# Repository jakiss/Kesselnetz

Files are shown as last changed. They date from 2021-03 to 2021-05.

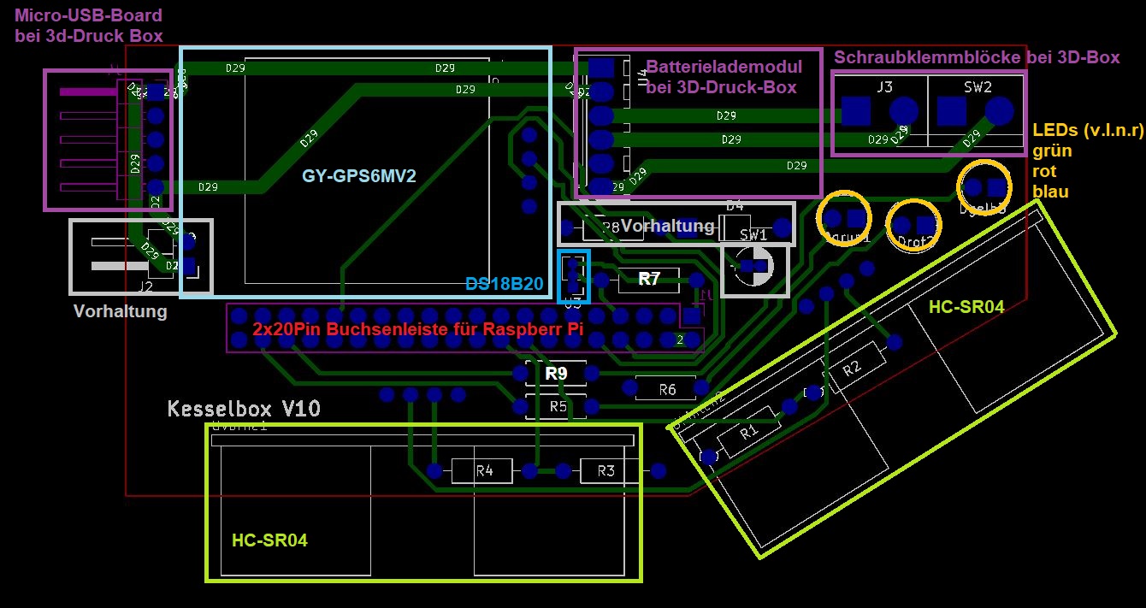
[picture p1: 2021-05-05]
Hardware/Platine_Draufsicht_1.JPG

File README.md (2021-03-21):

# Kesselbox
For the enlish version see below.

Das Projekt befasst sich mit der Entwicklung eines Radmessers nach der Idee des Tagesspiegel Berlin (Vgl. https://interaktiv.tagesspiegel.de/radmesser/ und https://github.com/tagesspiegel/radmesser). 

Die genaue des Beschreibung des Projekts mit Grundidee und Annahmen findet sich unter Projektbeschreibung.pdf, um eine kurze Zusammenfassung zu erhalten empfiehlt sich die Datei Zusammenfassung_Projektbeschreibung.pdf.

Das Projekt darf unter der GNU General Public License (GPL) verwendet werden.

------------------------------------------------------------
English version:

The project deals with the development of a measurement system for the overtaking distance between cars and bicycles after the idea of the Tagesspeigel Berlin (see https://interaktiv.tagesspiegel.de/radmesser/ and https://github.com/tagesspiegel/radmesser).

The detailed description of the project including the main idea and assumptions  can be found in Projektbeschreibung.pdf. For a short summary of the topic the file Zusammenfassung_Projektbeschreibung.pdf is recommended.

The project can be reused under the GNU General Public License (GPL).

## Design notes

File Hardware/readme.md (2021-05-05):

# Hardware

## Materialliste allgemein

| Komponentenname | Zahl pro Bausatz | Anmerkung |
| --- | --- | --- |
| Raspberry Pi Zero W | 1 | ohne vorgelötete Pins|
| Micro SD-Karte | 1 | mind. 16GB Class 10 |
| Buchsenleiste | 1 | 2x20 Pins 2,54mm RM |
| Steckerleiste | 1 | 2x20 Pins 2,54mm RM |
| Ultraschallsensoren | 2 | HC-SR04 |
| Widerstand | 2 | 510 Ohm |
| Widerstand | 2 | 1 kOhm |
| Widerstand | 1 | 4,7 kOhm |
| Widerstand | 3 | 100 Ohm |
| GPS-Modul | 1 | GY-GPS6MV2 mit Antenne |
| Temperatursensor | 1 | DS18B20 |
| Stiftleiste | 1 | 1x4 Pins RM 2,54 mm |
| LED | 3 | grün, rot, blau jeweils 5 mm |
| Powerbank | 1 | Kapazität von 5000 mAh empfohlen |

## Materialliste bei Montage in 3D-gedruckter Box (zusätzlich)

| Komponentenname | Zahl pro Bausatz | Anmerkung |
| --- | --- | --- |
| Akkus | 2 | 3,6V Wiederaufladbare Akkus 18650 (Flat-Top Li-Ion 3.6 V) |
| Akkuhalter | 1 | Passend für 2 Akkus 18650 |
| Micro-USB-Breakout-Board | 1 | |
| Steckerleiste | 1 | 1x5 Pin RM 2,54 mm |
| Batterielademodul | 1 | für Lithium Batterien 18650 (MakerHawk) |
| Steckerleiste | 1 | 1x6 Pin RM 2,54 mm |
| Wippschalter | 1 | |
| Schraubklemmblock | 2 | 2 polig RM 5,08 mm |
| Litze und Adernendhülsen | | Anschluss zwischen Schraubklemmblock und Schalter und Batteriehalter|

Powerbank wird nicht benötigt

# Montagereihenfolge

## allgemeine Montagereihenfolge

| Arbeitsschritt | zu verlötendes Bauteil |
| --- | --- |
| 1. | Wiederstände löten |
| 1.1 | 510 Ohm R2 und R4 |
| 1.2 | 1 kOhm R1 und R3 |
| 1.3 | 100 Ohm R5, R6 und R9 |
| 2. | LEDS löten, links grün, mitte rot, rechts blau |
| 3. | Buchsenleiste für Raspberry Pi anlöten, Raspberry Pi mit Steckerleiste versehen, Raspberry Pi erst zum Schluss aufstecken |
| 4. | Temperatursensor DS18B20 anlöten |
| 5. | GPS-Modul mit 4 Pin-Sitftleiste anlöten, Antenne befestigen | 
| 6. | Ultraschallsensoren anlöten |

## zusätzliche Schritte bei 3D-Druck-Box 

| Arbeitsschritt | zu verlötendes Bauteil |
| --- | --- |
| 1. | Batterielademodul mit 6-Pol-Stiftleiste verlöten |
| 2. | Micro-USB-Board mit 5-Pol-Stiftleiste verlöten |
| 3. | Schraubklemmenblock verlöten |
| 4. | Schalter an den rechten Schraubklemmenblock anschliessen |
| 5. | Batteriehalter an den linken Schraubklemmenblock anschliessen | 

# Software

| Arbeitsschritt | zu installierende Software-Komponente |
| --- | --- |
| 1. | Betriebssystem installieren - Raspbian wird mit Hilfe von Win32DiskImager auf die Micro-SD-Karte gespielt |
| 2. | Schnittstellen freigeben - in den Einstellungen werden I2C und die W-1 Schnittstellen freigegeben |
| 3. | Python-Code auf dem Raspberry Pi speichern |
| 4. | Test der Komponenten über die Testsoftware |
| 5. | Auto-Start definieren - in der Datei /etc/rc.local den Eintrag python3/Dateispeicherort/Dateiname & hinzufügen |

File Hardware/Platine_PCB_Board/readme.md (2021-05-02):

# Platine

Die Platine wurde mittels KiCad entworfen.

Die aktuellste Version stellt die V10 dar.

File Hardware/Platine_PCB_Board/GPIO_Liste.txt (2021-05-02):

GPIO16 (36) LED gelb
GPIO18 (12) LED grün
GPIO20 (38) LED rot
GPIO25 (22) Trigger
GPIO24 (18) Echo Vorne
GPIO23 (16) Echo Hinten
GPIO6  (31) Taster

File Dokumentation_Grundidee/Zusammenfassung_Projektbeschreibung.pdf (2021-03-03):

(T3 3000) – Jahrgang 2017

MESSSYSTEM ZUR BESTIMMUNG VON UBERHOLABST ¨ | ANDEN ¨

## VON KRAFTFAHRZEUGEN GEGENUBER FAHRRADFAHRERN ¨

Jakob Seitzer
Elektrotechnik, TEL17GR5, DHBW Stuttgart
Kurzfassung: Die Arbeit beschaftigt sich mit der Entwicklung eines Messsystems zur Ermittlung der ¨ | Uberhol- ¨
abstande von Kraftfahrzeugen gegen ¨ | uber Fahrradfahrern. Zur Bestimmung der seitlichen Abst ¨ | ande werden Ul- ¨
traschallsensoren (HC-SR04) verwendet, welche an einem Raspberry Pi Zero angebunden sind. Ein Temperatursensor (DS18B20) wird zur Kompensation der Temperaturabhangigkeit der Abstandsmessung verwendet. ¨ Das GPS-Modul GY-GPS6MV2 wird zur Bestimmung von Zeit und Position verwendet. Mit Hilfe einer Auswer-
tungssoftware werden Uberholvorg ¨ | ange aus den aufgezeichneten Daten extrahiert. ¨
Sch ¨usselworter: ¨ | Uberholabstand, Abstandsmessung, Ultraschallsensoren, HC-SR04, GPS-Modul ¨

Abstract: This student research project deals with the construction of a measurement system for recording overtakindg distances between motor wehicels and byciles. For measuring the distance on the left side of the bycile, two ultrasonic ranging sensors (HC-SR04) are used and connected to a Raspberry Pi Zero. A temperature sensor (DS18B20) is used for compensation of tempreature dependency of the distance measurement. The GPS-receiver GY-GPS6MV2 is used for detection of position and time. With a evaluation software the overtaking actions are detectet in the measured data.

Keywords: overtaking distance, distance measurement, ultra sonic raning module, HC-SR04, GPS-receiver

### 1 EINFUHRUNG ¨

Am 28.04.2020 trat die aktuell letzte Anderung der Straßenverkehrsordnung in Kraft. Zentrale Anpassung stellte ¨
hierbei die genaue Festlegung des Mindestuberholabstandes von Kraftfahrzeugen gegen ¨ | uber Fahrradfahrern ¨
dar. Innerorts muss beim Uberholen ein seitlicher Abstand von mindestens ¨ | | | 1,5 m eingehalten werden - außerorts
mindestens 2 m.
In einer groß angelegten Studie des Tagesspiegel Berlin aus dem Jahr 2018, wurde versucht die Uberholabst ¨ | ande ¨
gegenuber Fahrradfahrern in Berlin zu dokumentieren [ ¨ | 1]. Der entwickelte Radmesser ist nicht frei verfugbar. ¨
Aus diesem Grund konnen die Daten nicht unabh ¨ | angig gepr ¨ | uft werden. Es bestehen noch weitere Konzepte ¨
zur Konstruktion eines Radmessers, diese sind jedoch nicht vollstandig funktionsf ¨ | ahig [ ¨ | 2]. Um die Ergebnisse
der Studie des Tagesspiegels zu uberpr ¨ | ufen und auch Daten ¨ | uber andere St ¨ | adte zu erhalten, soll ein offenes ¨
Messsystem zu Erfassung der Uberholabst ¨ | ande entwickelt werden. ¨

### 2 SYSTEMBESCHREIBUNG

Fur das Erfassen der ¨ | Uberholabst ¨ | ande wird ein Messsystem entwickelt werden, welches am Fahrrad montiert ¨
wird und automatisch die Abstande nach links aufzeichnet. Mit Hilfe einer Software werden anschließend die ¨
Uberholabst ¨ | ande aus den gewonnenen Daten extrahiert. ¨

### 2.1 Hardwarekomponenten

Als zentrales Hardwareelement wird eine Recheneinheit benotigt, welche mit den Abstandssensoren kommu- ¨ nizieren kann. Um eine unabhangige und einfache Funktionsweise zu erreichen, wird mit dem Raspberry Pi ¨
Zero gearbeitet. Dieser stellt 40 GPIO-Pins zur Verfugung, an welche Sensoren angeschlossen werden k ¨ | onnen. ¨
Mit der Sprache Python 3 wird eine Software fur das Messsystem auf dem Raspberry Pi entwickelt. Auf der ¨ Micro-SD-Karte des Raspberry Pis werden die gemessenen Daten gespeichert werden.

Um den Uberholabstand zu erfassen werden zwei Ultraschallsensoren verbaut. Als Standardbauteil im unteren ¨
Preissegment fur Abstandssensoren bietet sich der Ultraschallsensor HC-SR04 an. Dieser erfasst zuverl ¨ | assig ¨
einen Messbereich zwischen 4 cm und 5 m und wird in vielen studentischen Projekten verwendet [3] [4]. Die Messung erfolgt nach einem Triggerimpuls von 10 µs. Es werden Schallwellen mit einer Frequenz von 40 kHz
ausgesendet und der Ruckmelde-Pin des Sensors geht auf ¨ | High. Wird der ausgegeben Schall innerhalb von

38 ms wieder empfangen, geht der Ruckmelde-Pin zum Empfangszeitpunkt wieder auf ¨ | Low, ansonsten nach
tmax = 38 ms.

Bei der Verwendung eines Ultraschallsensors muss die Temperaturabhangigkeit der Schallgeschwindigkeit be- ¨
rucksichtigt werden. Im Einsatzbereich des Messsystems ist mit Temperaturen zwischen ¨ | −10 °C und 35 °C, was
eine Abweichung der Schallgeschwindigkeit von bis zu 10 % zur Folge hat. Um die Temperaturabhangigkeit ¨ auszugleichen, wird die Temperatur mit dem Temperatursensor DS18B20 bestimmt. Dieser zeichnet sich durch
einen gunstigen Preis und eine weite Verbreitung in anderen Projekten aus [ ¨ | 5] [6].
Bei dem GPS-Modul, welches fur die Positions- und Zeitbestimmung ben ¨ | otigt wird, gibt es kaum etablierte ¨
Bauteile. Nach ausfuhrlicher Recherche fiel die Entscheidung auf das GPS-Modul NEO-6 der Firma u-blox. F ¨ | ur¨
die vereinfachte Konnektivitat hin zum Raspberry Pi Zero wird das Modul GY-GPS6MV2 verwendet, auf welchem ¨
der Chip NEO-6 verbaut ist. Dieses Modul ist kostengunstig erh ¨ | altlich und kann ¨ | uber die Universal Asynchronous ¨
Receiver Transmitter-Schnittstelle (UART) mit dem Raspberry verbunden werden [7].
Die Uberholvorg ¨ | ange werden durch die unterschiedlichen Zeitpunkte bestimmt, zu welchen das Kraftfahrzeug ¨
von den beiden Ultraschallsensoren erfasst wird. Um eine zeitlich unterschiedliche Erfassung durch die Ultraschallsensoren zu erreichen, mussen diese entweder in einem ausreichenden Abstand voneinander ent- ¨ fernt montiert sein, oder in zwei unterschiedliche Richtungen messen. Zuerst muss in diesem Zusammenhang bestimmt werden, welche maximale Distanz lmax ein Kraftfahrzeug zwischen zwei Messungen der Ul-
traschallsensoren zurucklegt. Innerhalb von St ¨ | adten ist mit einer maximalen Geschwindigkeitsdifferenz von ¨
vmax = 70 km h⁻¹ ≈ 19,44 m s⁻¹ zwischen Radfahrer und Kraftfahrzeug beim Uberholen zu rechnen. ¨
lmax = vmax · tmax = 0,038 ms · 19,44 m s⁻¹ = 0,739 m | (1)
Die Montage der beiden Ultraschallsensoren ist nicht in einem Abstand von 70 cm moglich, da der zur Verf ¨ | ugung ¨
stehende Platz auf dem Fahrrad begrenzt ist. Deshalb mussen die Ultraschallsensoren in zwei unterschiedliche ¨ Richtungen messen. Der minimale Winkel αmin, welchen die Ultraschallsensoren voneinander abgewandt sein
mussen, wird mit Hilfe der berechneten Strecke ¨ | lmax und einer angenommenen Messdistanz von lMess = 1,5 m
bestimmt. Es gilt die Annahme, dass bei α = 0° die Ultraschallsensoren das Kraftfahrzeug zeitgleich erkennen.

αmin = arctan

lmax

lMess

=

0,739 m
1,5 m
= 26,23° | (2)
Es besteht die Moglichkeit entweder einen Ultraschallsensor um mindestens ¨ | αmin = 26,33° vom anderen abzu-
wenden, oder beide um mindestens αmin/2 = 13,17° gegeneinander zu verstellen. Um genauere Messergebnisse zu erzielen, werden beide Ultraschallsensoren um αmin/2 verdreht. Bei dieser Montageart ist der Winkel zwischen Ultraschallsensor und Kraftfahrzeug geringer und die Messabweichung fallt geringer aus. ¨
Alle benotigten Bauteile werden auf eine in KiCad entwickelten Leiterplatte gel ¨ | otet. Dies bietet sowohl die ¨
Moglichkeit einer dauerhaften und sicheren Montage, als auch eine exakte Positionierung der Ultraschallsen- ¨
soren bezuglich des Winkels ¨ | α.

### 2.2 Software f ¨ur das Messsystem

Wie bereits oben beschrieben, kann auf dem Raspberry Pi ein Programm in Python 3 entwickelt werden. Drei zentrale Anforderungen muss das Programm erfullen: ¨

1. Moglichst viele Abstandsmessungen ¨
2. Hohe Ausfallsicherheit
3. Hohe Datensicherheit
Moglichst viele Messungen ¨ | mit den Ultraschallsensoren sorgen fur eine solide Datenlage. Hierf ¨ | ur werden ¨
die beiden Ultraschallsensoren durch den selben Impuls getriggert, sie starten zeitgleich ihre Messungen.
Die Ruckmelde-Pins werden durch die Software ¨ | uberwacht. Sobald einer der beiden Pins auf ¨ | High ist, wird
dieser Zeitpunkt als Startzeitpunkt fur den Ultraschallsensor verwendet. Befinden sich beide R ¨ | uckmelde-Pins ¨
im High-Zustand, wird uberwacht, wie lange sie in diesem Zustand verbleiben. F ¨ | allt ein R ¨ | uckmelde-Pin wie- ¨
der auf Low, ist dessen Messung beendet und die Zeit tMess, kann zusammen mit der Schallgeschwindigkeit cSchall = 340 m s⁻¹ zur Ermittlung der Messdistanz verwendet werden. Unter Berucksichtigung, dass der Schall ¨
in der Zeit tmess sowohl Hin- als Ruckweg zum Kraftfahrzeug zur ¨ | uck gelegt hat, bestimmt sich die Entfernung ¨
des KFZ lMess zu

lMess =

1
- tMess · cSchall | (3)

Sobald beide Ultraschallsensoren ihre Messung beendet haben und das Messergebnis in einer CSV-Datei gespeichert wurde, wird unmittelbar im Anschluss wieder eine neue Messung initiiert. Das Erfassen der Zeit und Postion ist weniger oft notwendig, da zwischen zwei erfassten Positionen interpoliert werden kann, solange diese nicht zu weit voneinander entfernt sind. Als maximaler zeitlicher Abstand tGP Smax ergibt sich aus einem
maximalen raumlichen Abstand, bei welchem noch interpoliert werden kann, von ¨ | lGP Smax = 20 m und einer
maximalen Geschwindigkeit des Fahrradfahrers von vbikemax = 30 km h⁻¹ = 8,33 m s⁻¹
| :

tGP Smax =

lGP Smax

vbikemax

| | = 2,4 s | (4)

Die Temperaturmessung nimmt eine Zeit von bis zu 750 ms in Anspruch [6] und wird deshalb nur in Minuten-
abstanden durchgef ¨ | uhrt. Eine starke Temperaturschwankung ist w ¨ | ahrend einer Fahrradfahrt nicht zu erwarten, ¨
jedoch zwischen verschiedenen Fahrten. Um den Speicherverbrauch moglichst gering zu halten, wird drauf ¨ verzichtet die Postions- und Temperaturdaten zu jedem Messwert der Ultraschallsensoren hinzuzufugen. Diese ¨ werden lediglich einmal als eigene Zeile zum Zeitpunkt der Messung abgelegt.
Ein Eingriff in das Messsystem ist wahrend des Betriebs nicht m ¨ | | oglich und macht deshalb eine ¨ | hohe Ausfallsi-
cherheit erforderlich. Daten mussen zuverl ¨ | assig aufgezeichnet werden. Aus diesem Grund ist ein Stehenbleiben ¨
oder Abbruch des Programms zu verhindern. Durch das sofortige und standige Wiederholen der Messungen ¨ mit den Ultraschallsensoren besteht die Gefahr, dass nicht alle Messungen reibungslos Ablaufen. Wird ein Triggerimpulses nicht korrekt erkannt, wird der normale Messzyklus durchbrochen. Durch Uberwachung der Zeit, ¨
welche das Programm fur eine Abstandsmessung ben ¨ | otigt, wird beim ¨ | Uberschreiten einer Zeitgrenze von ¨ | 50 ms
die Messung beendet. Zudem wird dem Benutzer durch eine Betriebsstatusanzeige bestehend aus zwei LEDs signalisiert, ob ein reibungsloser Programmdurchlauf gewahrleistet ist. Zu Programmstart werden die einzelnen ¨ Komponenten getestet, bevor die Statusanzeige auf betriebsbereit (grune LED) wechselt. Wird ein Sensor als ¨ fehlend oder fehlerhaft erkannt, wird dies dem Nutzer durch eine rote LED signalisiert. Eine Problembehebung muss im Einzelfall erfolgen.

Wahrend einer Messfahrt sind verschiedene Szenarien denkbar, welche zu einem Absturz des Raspberry Pis ¨
fuhren k ¨ | onnen und nicht softwaretechnisch abgefangen werden k ¨ | onnen. Ein Spannungsausfall, entweder durch ¨
eine leere Powerbank oder das Herausrutschen eines Kabels sind ebenso denkbar, wie ein Unfall und eine damit einhergehende Beschadigung des Messsystems bzw. der Recheneinheit. Um die bis zu diesem Zeitpunkt ¨ erfassten Daten nicht zu verlieren, ist eine hohe Datensicherheit erforderlich. In diesem Zusammenhang ist zu berucksichtigen, dass die Datei, welche zum Zeitpunkt des Programmabsturzes beschrieben wird, unbrauchbar ¨ wird und alle darin enthaltenen Daten verloren gehen. Um den Datenverlust zu minimieren, wird nach einer festgelegten Zahl an Messungen (5000) die bisherige Datei geschlossen und eine neue Datei mit fortlaufender Nummerierung erstellt, in welche die neuen Daten gespeichert werden. So gehen maximal 5000 Messwerte verloren, das bedeutet die Messwerte von maximal zwei Minuten.

### 2.3 Auswertungssoftware f ¨ur die Messdaten

Als Auswertungsgrundlage dienen die durch die Messsoftware erstellten CSV-Dateien, welche die gemessenen Abstandswerte, Positionen und Temperaturen beinhalten. Nach dem anfanglichen Einlesen der gemessenen ¨ Daten, welches das Zuweisen der Positions- und Temperaturdaten zu den Abstandsmesswerten beinhaltet, so-
wie die Glattung der gemessenen Abst ¨ | ande, werden diese auf ¨ | Uberholvorg ¨ | ange untersucht. Kennzeichnend ¨
fur¨ Uberholvorg ¨ | ange ist ein Abfallen des Messwerts des hinteren Ultraschallsensors, w ¨ | ahrend der vordere Ul- ¨
traschallsensor weiterhin eine große Distanz erfasst. Danach ermitteln beide Ultraschallsensoren den gleichen kleinen Abstandswert, da sich das Kraftfahrzeug genau neben dem Fahrrad befindet und von beiden Ultraschallsensoren erfasst wird. Zum Ende des Uberholvorgangs steigt der Messwert des hinteren Ultraschallsensors an, ¨ wohingegen der vordere Ultraschallsensor weiterhin das Kraftfahrzeug erfasst und einen kleinen Messwert liefert.
Da jedem Uberholvorgang GPS-Koordinaten zugeordnet sind, ist eine Analyse der ¨ | Uberholvorg ¨ | ange nach Re- ¨
gionen moglich. Um eine exakte regionale Analyse zu erhalten werden die Koordinaten in Adressen bestehend ¨ aus Stadt, Postleitzahl und Straße umgewandelt. Anhand dieser Informationen kann ein Vergleich zwischen
verschiedenen Stadten erfolgen. Innerhalb einzelner St ¨ | adte k ¨ | onnen besonders gef ¨ | ahrliche Straßenabschnitte ¨
erkannt werden. Um die GPS-Koordinaten in Adressen umzuwandeln wird eine Programmierschnittstelle ver-
wendet (Application Programming Interface - API). Aus Kosten- und Kompatibilitatsgr ¨ | unden wird mit der API von ¨
OpencageGeocoder gearbeitet. Nach Ubergabe der Koordinaten wird die dazugeh ¨ | orige Straße gesucht und ¨
die gefundene Adresse mit Informationen uber die Straße (Straßentyp, erlaubte Geschwindigkeit, Anzahl der ¨
Fahrspuren) zuruckgegeben [ ¨ | 8].

### 3 TESTS

### 3.1 Hardwaretests

HC-SR04

la=Messdistanz

lb=seitliche Abweichung

# lc=gemessene Distanz

β

Abbildung 1: Messbereich | der | Ultraschallsensoren
HC-SR04, in Farbe die eingesetzten Objekte

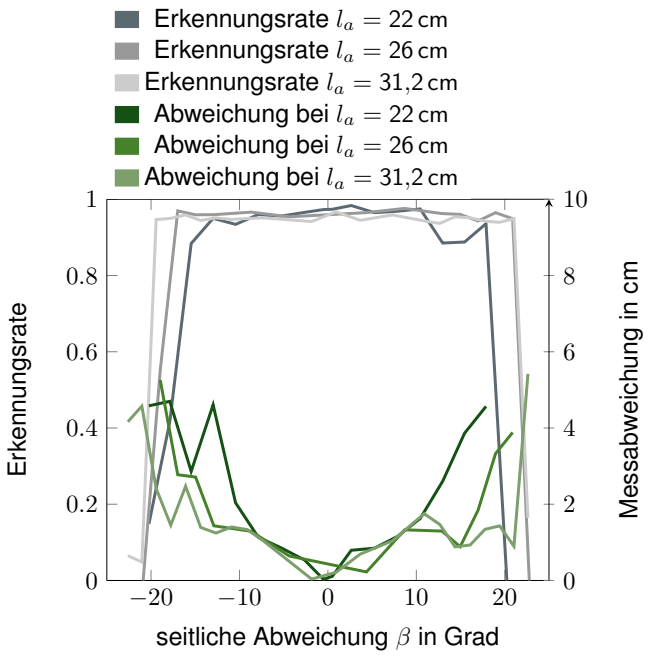
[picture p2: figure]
seitliche Abweichung β in Grad; Erkennungsrate; Messabweichung in cm; Erkennungsrate la = 22 cm Erkennungsrate la = 26 cm Erkennungsrate la = 31,2 cm Abweichung bei la = 22 cm Abweichung bei la = 26 cm Abweichung bei la = 31,2 cm

Abbildung 2: Messbereich der Ultraschallsensoren bei verschiedenen la

Die Ultraschallsensoren mussen hinsichtlich ihres Messbereichs untersucht werden. Durch Tests muss nachge- ¨ wiesen werden, dass die Ultraschallsensoren auch Objekte erfassen, welche nicht senkrecht vor den Ultraschall-
sensoren stehen. In diesem Zusammenhang wird untersucht, inwiefern eine schrage Messfl ¨ | ache (Vgl. Abb. ¨ | 3)
die Messungen beeinflusst und welchen Einfluss ein Abweichen aus der Messsenkrechten (Vgl. Abb. 1) auf die Messergebnisse hat.

In Abb. 1 ist die seitliche Abweichungen eines Objekts von der Messsenkrechten dargestellt. Der Winkel β stellt den Messbereich dar und berechnet sich zu

β = arctan
lb
la
(5)
In Abb. 2 ist die Erkennungsrate in Abhangigkeit der seitlichen Abweichung ¨ | β dargestellt. Die Erkennungsrate ist
definiert als Anteil der Messungen, bei welcher das Objekt erkannt wird. Die Messabweichung ergibt sich aus der
tatsachlich gemessenen Distanz abz ¨ | uglich ¨ | lc. Fur die in Abb. ¨ | 2 dargestellten Punkte, wurden jeweils mindestens
40 000 Messungen durchgefuhrt und per Software ausgewertet. Bei steigender Messdistanz ¨ | la vergroßert sich ¨
der Messbereich β leicht. Zu beobachten ist, dass bis zu einem Winkel β von bis zu 19° ein Objekt zuverlassig ¨ erkannt wird. Die Messabweichung steigt bereits bei β > 16° stark an.
In Abb. 3 ist der Versuchsaufbau fur eine schr ¨ | age Messfl ¨ | ache skizziert. Der Winkel ¨ | γ stellt die Schrage der ¨
Messflache gegen ¨ | uber einer normalen Messfl ¨ | ache, senkrecht zur Messrichtung der Ultraschallsensoren dar. In ¨
Abb. 4 sind die Erkennungsrate und die Messabweichung fur variable Messdistanzen ¨ | la in Abhangigkeit des ¨
Winkels γ dargestellt. Es gelten die selben Definitionen wie oben. Bei steigender Messdistanz la verkleinert sich die Erkennungsrate bei einem Winkel von β ≥ 30° leicht. Die Messabweichung steigt ebenfalls mit zunehmender Schrage ¨ γ der Messflache an. ¨

Das Zunehmen der Messabweichung ist mit dem Erkennungswinkel β der Ultraschallsensoren zu begrunden. ¨
Wird die Messflache mit dem Winkel ¨ | γ schrager aufgestellt, r ¨ | uckt ein Teil der Messfl ¨ | ache innerhalb des Erken- ¨
nungsbereichs naher an den Ultraschallsensor (Vgl. Abb. ¨ | 3, grau gestrichelter Bereich).

HC-SR04

la=Messdistanz

γ

Abbildung 3: Messgenauigkeit bei schragen Fl ¨ | achen, ¨
in Farbe die neuen Messflachen ¨

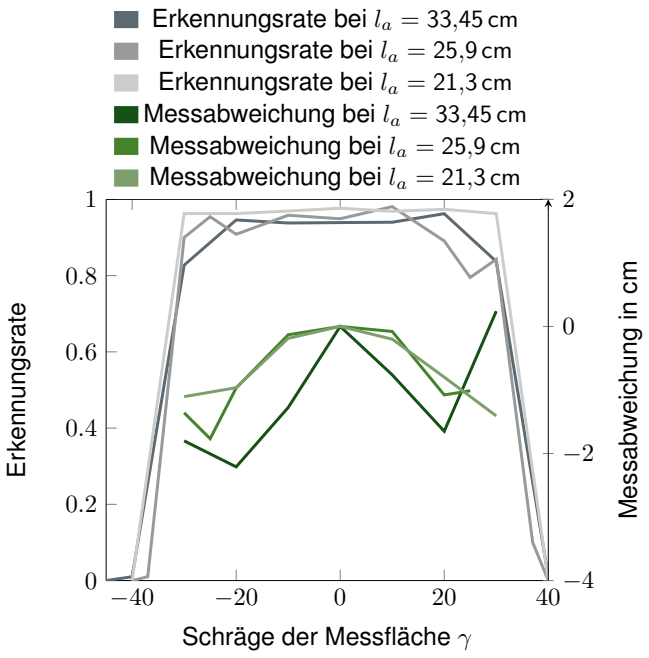
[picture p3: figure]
Schrage der Messfl ¨; ache ¨; Erkennungsrate; Messabweichung in cm; Erkennungsrate bei la = 33,45 cm Erkennungsrate bei la = 25,9 cm Erkennungsrate bei la = 21,3 cm Messabweichung bei la = 33,45 cm Messabweichung bei la = 25,9 cm Messabweichung bei la = 21,3 cm

Abbildung 4: Genauigkeit der Messungen mit Ultraschallsensoren bei schragen Reflexions- ¨ flachen ¨

Es ist festzuhalten, dass die Ultraschallsensoren Objekte erkennen konnen, welche bis zu ¨ | β = 19° aus der
Messsenkrechten abweichen. Die Schrage der Messfl ¨ | ache spielt bei ¨ | γ ≤ 19° eine untergeordnete Rolle. Fur eine ¨
zuverlassige Objekterkennung mit vernachl ¨ | assigbaren Messabweichungen muss der Winkel ¨ | α/2 (Vgl. oben)
kleiner als der Winkel β des Messbereichs sein. Es gilt:

αmax
2
≤ β = 19° | (6)

Bei verschiedenen Tests stellte sich ein Winkel von α/2 = 16° als optimal heraus.

### 3.2 Softwaretest Messsystem

Fur das Messsystem ist ein stabiler Programmablauf sowie das Behandeln von fehlerbehafteten Messwerten ¨
und Sensorausfallen wichtig. Ein Fortlauf des Programms sowie eine nachtr ¨ | agliche Bearbeitungsm ¨ | oglichkeit f ¨ | ur¨
fehlerhafte Messergebnisse stehen im Vordergrund.

In diesem Zusammenhang ist ein Langzeittest erforderlich, um Fehler zu erkennen, welche nicht bereits bei
Programmstart auftreten. Unabhangig der Programmlaufzeit sind keine zus ¨ | atzlichen Fehler aufgetreten. Nach ¨
rund 20 Stunden ist die Powerbank, welche zur Spannungsversorgung verwendet wird, erschopft. ¨

Beim GPS-Modul sind zwei unterschiedliche Fehler moglich. Es kann zu einem kurzfristigen Signalabbruch ¨ kommen oder zu einem dauerhaften Komplettausfall. In beiden Fallen wird der Programmablauf nicht negativ ¨ beeinflusst. Sind die GPS-Daten nur kurzfristig nicht verfugbar, kann zwischen den anderen Koordinaten in- ¨
terpoliert werden. Bei einem dauerhaften Sensorausfall hingegen ist es nicht mehr moglich ¨ | Uberholvorg ¨ | ange ¨
geografisch zu verorten.

Die Ultraschallsensoren konnen verschiedene Fehler aufweisen. Bei einzelnen Messungen kann es zu falschen ¨
Messergebnissen kommen, die Ultraschallsensoren konnen verdeckt oder verschmutzt sein oder sie k ¨ | onnen ¨
komplett ausfallen. Das Programm des Messsystems wird nicht durch falsche Signale der Ultraschallsensoren beeinflusst, da durch einen Zeitabgleich auch ohne Rucksignal der Ultraschallsensoren mit neuen Messungen ¨ fortgefahren wird. Fehlerhafte Messergebnisse, welche außerhalb des Messbereichs der Ultraschallsensoren
liegen konnen durch die Auswertungssoftware aussortiert werden und einzelne abweichende Messwerte k ¨ | onnen ¨
durch die Auswertungssoftware korrigiert werden (Vgl. Glattung). Ein Komplettausfall eines Ultraschallsensors ¨
fuhrt zu einem fatalen Fehler bei der Erkennungssoftware, da diese zur Erkennung von ¨ | Uberholvorg ¨ | angen auf ¨
die unterschiedlichen Messergebnisse der Ultraschallsensoren angewiesen ist.

### 3.3 Softwaretest Auswertungssoftware

Die Auswertungssoftware wird mit gezielt durchgefuhrten ¨ | Uberholvorg ¨ | angen getestet. Die ¨ | Uberholvorg ¨ | ange ¨
wurden mit einem moglichst exakten seitlichen Abstand durchgef ¨ | uhrt, aufgrund von Lenkfehlern von Autofahrer ¨
und Fahrradfahrer, konnte die Distanz jedoch nicht exakt eingehalten werden. Die Auswertungssoftware er-
kannte die Uberholvorg ¨ | ange aus den aufgezeichneten Daten, kleine Abweichungen waren bei der ermittelten ¨
Distanzen zu erkennen. An Stellen ohne Uberholvorg ¨ | ange wurden keine ¨ | Uberholvorg ¨ | ange extrahiert. Die Funk- ¨
tion der Software wurde somit fur beide Richtungen nachgewiesen, korrektes Erkennen aber keine zu große ¨ Sensitivitat. ¨

### 4 FAZIT

Es wurde ein Messsystem zur Erfassung der seitlichen Uberholabst ¨ | ande von Kraftfahrzeugen gegen ¨ | uber Fahr- ¨
radfahrern entwickelt. Uberholvorg ¨ | ange werden durch die Auswertungssoftware automatisch erkannt und regio- ¨
nal verortet. Die Funktion des Messsystems wurde durch mehreren Testreihen nachgewiesen.

Weitere Tests mit verschiedenen Arten von Kraftfahrzeugen sind notwendig, genauso wie das Testen der Aus-
wertungsmoglichkeiten, sobald Daten ¨ | uber viele ¨ | Uberholvorg ¨ | ange vorliegen. ¨

LITERATUR

[1] Tagesspiegel Online. (2018). “radmesser”, Verlag Der Tagesspiegel GmbH, Adresse: https://interaktiv.tagesspiegel.de/radmesser/index.html (https://interaktiv.tagesspiegel.de/radmesser/index.html) (besucht am 12. 12. 2019).
[2] Zweirat Stuttgart. (2020). “Friends of Open Bike Sensor, Citizen Science Project by Zweirat Stuttgart”, Adresse: https://github.com/Friends-of-OpenBikeSensor (besucht am 28. 05. 2020).
[3] K. A. Raza und W. Monnet, “Moving objects detection and direction-finding with HC-SR04 ultrasonic linear array”, in 2019 International Engineering Conference (IEC), 2019, S. 153–158.
[4] D. Vakula und Y. K. Kolli, “Low cost smart parking system for smart cities”, in 2017 International Conference on Intelligent Sustainable Systems (ICISS), 2017, S. 280–284.
[5] W. Jingzhuo und G. Chenglong, “Research on 1-Wire Bus Temperature Monitoring System”, in 2007 8th International Conference on Electronic Measurement and Instruments, 2007, S. 3–722–3–726.
[6] B. Huang, J. Lei und Y. Bo, “The reading data error analysis of 1-wire bus digital temperature sensor DS18B20”, in 2012 Proceedings of International Conference on Modelling, Identification and Control, Wuhan, Hubei, China, Juni 2012, S. 433–436, ISBN: 978-1-4673-1524-1.
[7] H. Fu, G. Xiong, S. Chen, M. Qiu, H. Xiong, Z. Shen, X. Dong, X. Su und X. Guo, “Design of Low-cost Position Differential Positioning System Based on STM32”, in 2018 Chinese Automation Congress (CAC), 2018, S. 1420–1425. DOI: 10.1109/CAC.2018.8623492. (https://doi.org/10.1109/CAC.2018.8623492)
[8] OpenCage GmbH. (2020). “OpenCage Geocoder”, Adresse: https://opencagedata.com/ (besucht am
12. 05. 2020).

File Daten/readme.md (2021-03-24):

# Stelle für Datenübergabe

## Daten aus der Kesselbox

Die Daten aus der Kesselbox heißen messdatenX.txt, wobei X eine fortlaufende natürliche Zahl ist.
GPS-Daten liegen im GPRMC-Format vor, wie sie durch das GPS-Modul übermittelt werden.
Es werden keine Überschriften verwendet.

| Spalteninhalt | Beispieldaten | Zweck der Daten |
|---|---|---|
| Zeit in Sekunden seit Systemstart | 158.689 | Genaue Bestimmung der Überholvorgänge |
| Messwert vorderer Ultraschallsensor in Zentimeter | 12050.34 | Bestimmung der Überholvorgänge |
| Messwert hinterer Ultraschallsensor in Zentimeter | 145.65 | Bestimmung der Überholvorgänge |

## Überholvorgänge

enthalten in erkannte.csv

Die Daten enthalten alle durch die Auswertungssoftware erkannten Überholvorgänge mit den entsprechenden Daten bezüglich Ort und Datum.
Bisher ist die Reihenfolge der Spalten noch für die folgende Software von Bedeutung.

| Spaltenname | Beispieldaten | Spalteninhalt |
| --- | --- | --- |
| Abstand | 156.43 | gemessener Abstand in Zentimeter - Durchschnittswert der gemessenen Abstandswerte während sich das Auto links neben dem Fahrrad befindet  - dabei ist der Abstand zwischen Fahrradmitte und Hauptfläche des Autos angegeben |
| Zeit | 120934 | UTC-Zeit, ohne Berücksichtigung von Sommer- und Winterzeit, sowie Zeitverschiebung im Format HMMSS oder HHMMSS |
| Datum | 21220 | Datum, übermittelt durch GPS-Modul im Format TMMYY oder TTMMYY|
| Lange | 48.6564 | Breitengrad angegeben in Grad, wenn südlich vom Äquator, dann negative Werte |
| Breite | 9.4543 | Längengrad angegeben in Grad, wenn westlich vom Nullmeridian, dann negative Werte |
| Geschwindigkeit Fahrrad | 17.96| Geschwindigkeit des Fahrrads in km/h, wird aus Angaben des GPS-Moduls bestimmt |
| Geschwindigkeit KFZ | | Berechung bisher noch nicht funktionsfähig |
| Lange KFZ | | Berechnung bisher nocht nicht funktionsfähig |
| checksumme | 23890867 | Berechnung erfolgt, um Dopplungen bei Überholvorgängen zu verhindern |

## Überholvorgänge mit Adressen

Adressen werden über die API von opencage (https://opencagedata.com/)  aus den GPS-Koordinaten bestimmt.

| Spaltenname | Beispieldaten | Spalteninhalt |
| --- | --- | --- |
| Number | 5 | Nummer des Überholvorgangs |
| Distance | 164.507 | Gemessener Abstand in Zentimeter - Durchschnitsswert der gemessenen Abstandswerte während sich das Auto links neben dem Fahrrad befindet - dabei ist der Abstand zwischen Fahrradmitte und Hauptfläche des Autos angegeben |
| LAT | 48.6799 | Breitengrad angegeben in Grad, wenn südlich vom Äquator, dann negative Werte |
| LON | 9.11712 | Längengrad angegeben in Grad, wenn westlich vom Nullmeridian, dann negative Werte |
| LAT_corrected |  | korrigierter Breitengrad (Vgl. LAT) |
| LON_corrected |  | korrigierter Längengrad (Vgl. LON) |
| speed | | bisher enthalten, Default-Wert steht auf 0, noch nicht vollständig implementiert|
| date | 270820 | Datum im Format DDMMYY oder DMMYY|
| date_format | 2020-08-27 | YYYY-MM-DD |
| time | 45553 | UTC-Uhrzeit im Format HMMSS oder HHMMSS |
| time_format | 04:55:13 | UTC-Uhrzeit im Format HH:MM:SS |
| country | Deutschland | Land abgefragt über die API von opencage |
| state | Baden-Württemberg | Bundesland oder in anderen Ländern Vergleichbares, abgefragt über die API von opencage |
| county | Landkreis Esslingen | Landkreis oder in anderen Ländern Vergleichbares, abgefragt über die API von opencage |
| suburb | Degerloch | Teilort abgefragt über die API von opencage, zur genauen Unterscheidung der Adresse in großen Städten |
| citytown | Stuttgart | Stadt abgefragt über die API von opencage |
| postcode | 70771 | Postleitzahl abgefragt über die API von opencage |
| roadname | Azenbergstraße | Straßenname abgefragt über die API von opencage |
| roadtype | residential | Straßenkategorie abgefragt über die API von opencage - Definition von openstreetmaps |
| oneway | yes | Einbahnstraße abgefragt über die API von opencage |
| maxspeed | 40 | maximal erlaubte Geschwindigkeit abgefragt über die API von opencage |
| speedin | km/h | Einheit für die maximal erlaubte Geschwindigkeit abgefragt über die API von opencage |
| lanes | 2 | Zahl der Spuren der entsprechenden Straße abgefragt über die API von opencage |
| bikespeed | 16.678 | Geschwindigkeit des Fahrradfahrers in km/h |

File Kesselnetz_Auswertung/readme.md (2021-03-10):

# Eingabe

Es werden die durch die Kesselnetz aufgezeichneten Daten eingegeben (Vgl. Daten - messdatenX.txt).
Die Dateien müssen fortlaufend nummeriert sein.

# Verarbeitung

Die Dateien werden nacheinander eingelesen und es werden die Abstandswerte ausgewertet.
Lassen die Abstandswerte den Rückschluss zu, dass ein Überholvorgang stattgefunden hat, wird dieser zwischengespeichert.
Die Software wurde in R erstellt.

# Ausgabe
Die zuvor erkannten Überholvorgänge werden zusammen mit den GPS-Koordinaten in eine Datei mit dem Namen erkannte.csv (Vgl. Daten) geschrieben.

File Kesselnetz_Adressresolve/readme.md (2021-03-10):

# Eingabe

Eingabe ist die CSV-Datei mit den Überholvorgängen und den GPS-Daten.
Aktuell ist die Spaltenreihenfolge von Bedeutung.

# Verwendete Software

Die Abfrage der Adressen erfolgt über die API von opencage, welche in einem R-Skript mit Hilfe von: (https://docs.ropensci.org/opencage/) bzw. (https://github.com/juliusgh/opencage) 
ausgeführt wird.

# Ausgabe

Ausgegeben werden die Daten als CSV-Datei, wobei jetzt aus den GPS-Daten Adressen generiert werden und die entsprechenden Informationen über die Straßen abgefragt werden. 
Zudem werden Datum und Uhrzeit in ein interpretierbares Format übersetzt.

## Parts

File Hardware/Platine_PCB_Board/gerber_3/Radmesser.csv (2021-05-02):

ID | Bezeichner | Gehäuse | Stückzahl | Bezeichnung | Anbieter und Referenz
1 | Uvorne1,Uhinten2 | XCVR_HC-SR04 | 2 | HC-SR04
2 | Drot2,Dgrun1 | LED_D5.0mm | 2 | LED
3 | GPS1 | GY-GPS6MV | 1 | GY-GPS6MV2
4 | J1 | PinSocket_2x20_P2.54mm_Vertical | 1 | Raspberry_Pi_2_3
5 | U3 | Pin_Header_Straight_1x03_Pitch1.27mm | 1 | DS18B20
6 | SW1 | CP_Radial_D4.0mm_P1.50mm | 1 | SW_DIP_x01
7 | R1,R3 | R_Axial_DIN0207_L6.3mm_D2.5mm_P10.16mm_Horizontal | 2 | 1k
8 | R2,R4 | R_Axial_DIN0207_L6.3mm_D2.5mm_P10.16mm_Horizontal | 2 | 510
9 | R5,R6 | R_Axial_DIN0207_L6.3mm_D2.5mm_P10.16mm_Horizontal | 2 | 100
10 | R7 | R_Axial_DIN0207_L6.3mm_D2.5mm_P10.16mm_Horizontal | 1 | 4,7k
11 | R8 | R_Axial_DIN0207_L6.3mm_D2.5mm_P10.16mm_Horizontal | 1 | 10k

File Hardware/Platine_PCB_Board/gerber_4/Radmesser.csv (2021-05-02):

ID | Bezeichner | Gehäuse | Stückzahl | Bezeichnung | Anbieter und Referenz
1 | R6,R5,R9 | R_Axial_DIN0207_L6.3mm_D2.5mm_P7.62mm_Horizontal | 3 | 100
2 | Uvorne1,Uhinten2 | XCVR_HC-SR04 | 2 | HC-SR04
3 | Drot2,Dgrun1,Dgelb3 | LED_D5.0mm | 3 | LED
4 | GPS1 | GY-GPS6MV | 1 | GY-GPS6MV2
5 | J1 | PinSocket_2x20_P2.54mm_Vertical | 1 | Raspberry_Pi_2_3
6 | U3 | Pin_Header_Straight_1x03_Pitch1.27mm | 1 | DS18B20
7 | SW1 | CP_Radial_D4.0mm_P1.50mm | 1 | SW_DIP_x01
8 | R1,R3 | R_Axial_DIN0207_L6.3mm_D2.5mm_P10.16mm_Horizontal | 2 | 1k
9 | R2,R4 | R_Axial_DIN0207_L6.3mm_D2.5mm_P10.16mm_Horizontal | 2 | 510
10 | R7 | R_Axial_DIN0207_L6.3mm_D2.5mm_P10.16mm_Horizontal | 1 | 4,7k
11 | R8 | R_Axial_DIN0207_L6.3mm_D2.5mm_P10.16mm_Horizontal | 1 | 10k

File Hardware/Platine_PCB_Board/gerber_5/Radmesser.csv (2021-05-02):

ID | Bezeichner | Gehäuse | Stückzahl | Bezeichnung | Anbieter und Referenz
1 | R6,R5,R9 | R_Axial_DIN0207_L6.3mm_D2.5mm_P7.62mm_Horizontal | 3 | 100
2 | Uvorne1,Uhinten2 | XCVR_HC-SR04 | 2 | HC-SR04
3 | Drot2,Dgrun1,Dgelb3 | LED_D5.0mm | 3 | LED
4 | U3 | Pin_Header_Straight_1x03_Pitch1.27mm | 1 | DS18B20
5 | SW1 | CP_Radial_D4.0mm_P1.50mm | 1 | SW_DIP_x01
6 | R1,R3 | R_Axial_DIN0207_L6.3mm_D2.5mm_P10.16mm_Horizontal | 2 | 1k
7 | R2,R4 | R_Axial_DIN0207_L6.3mm_D2.5mm_P10.16mm_Horizontal | 2 | 510
8 | R7 | R_Axial_DIN0207_L6.3mm_D2.5mm_P10.16mm_Horizontal | 1 | 4,7k
9 | R8 | R_Axial_DIN0207_L6.3mm_D2.5mm_P10.16mm_Horizontal | 1 | 10k
10 | D4 | D_T-1_P10.16mm_Horizontal | 1 | Z5,1V
11 | J2 | Pin_Header_Angled_1x02_Pitch2.54mm | 1 | Conn_01x02_Female
12 | GPS1 | GY-GPS6MV | 1 | GY-GPS6MV2
13 | U4 | BatCharging | 1 | Battery_Charging
14 | J1 | Raspi_Zero | 1 | Raspberry_Pi_2_3
15 | J3 | TerminalBlock_bornier-2_P5.08mm | 1 | Conn_01x02_Female
16 | SW2 | TerminalBlock_bornier-2_P5.08mm | 1 | SW_on_off
17 | J4 | Pin_Header_Angled_1x05_Pitch2.54mm | 1 | USB_B_Micro

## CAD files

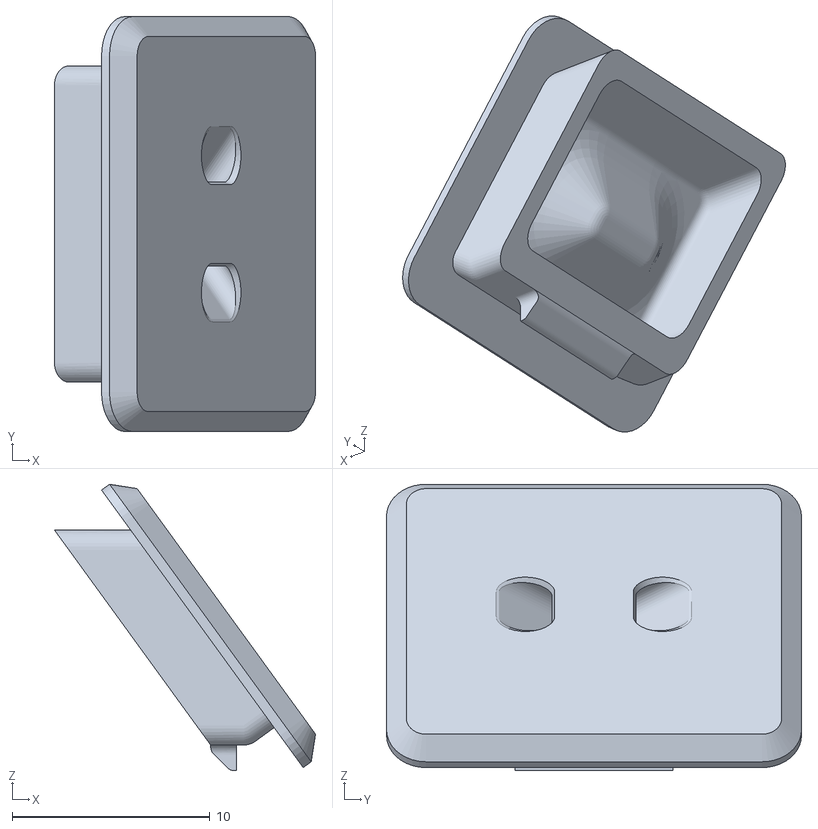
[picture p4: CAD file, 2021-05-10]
Hardware/3D-Druck-Daten/1.4_USB_Stopfen.stl
13.2 x 21.0 x 14.5

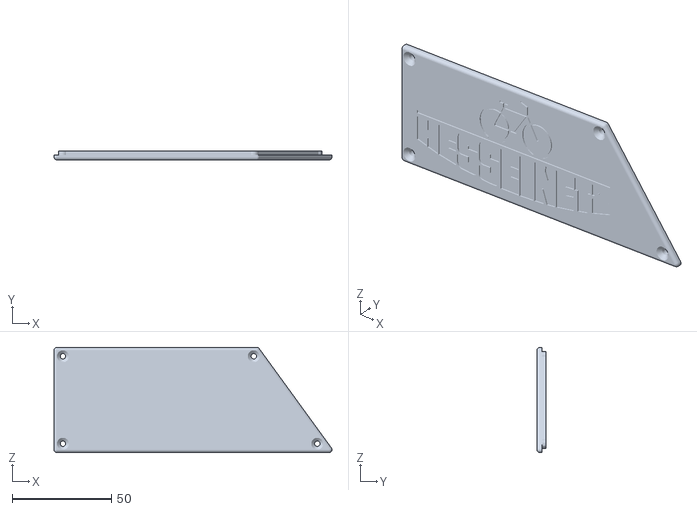
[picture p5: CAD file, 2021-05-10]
Hardware/3D-Druck-Daten/1.4_Deckel.stl
139.9 x 4.50 x 53.0

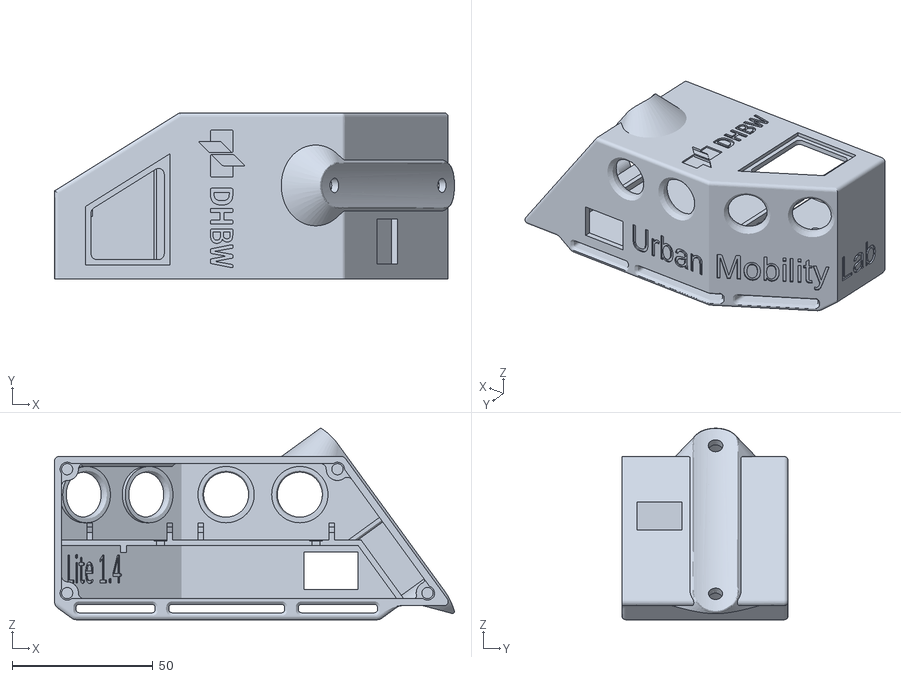
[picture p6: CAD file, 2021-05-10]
Hardware/3D-Druck-Daten/1.4_Gehäuse.stl
142.1 x 59.2 x 68.1

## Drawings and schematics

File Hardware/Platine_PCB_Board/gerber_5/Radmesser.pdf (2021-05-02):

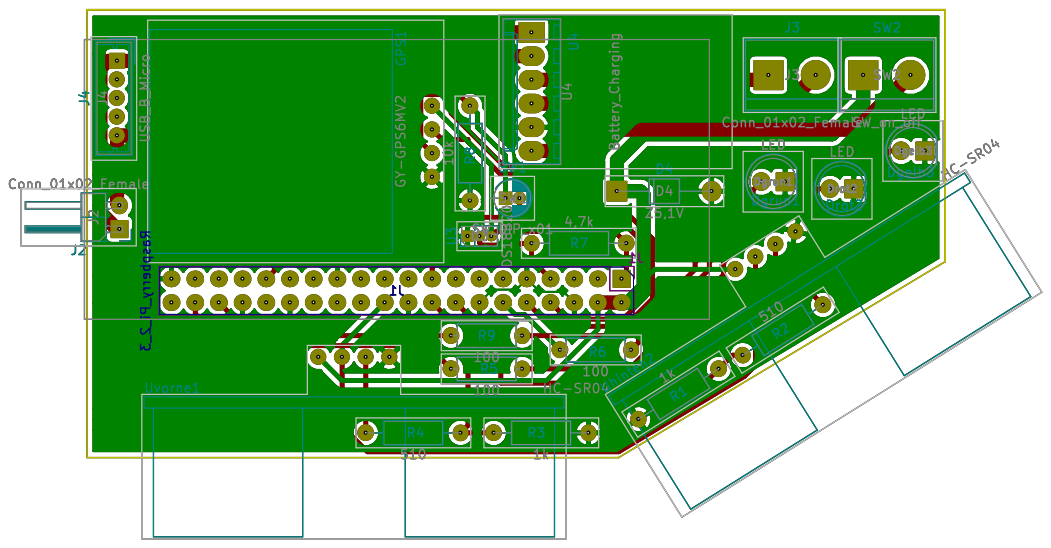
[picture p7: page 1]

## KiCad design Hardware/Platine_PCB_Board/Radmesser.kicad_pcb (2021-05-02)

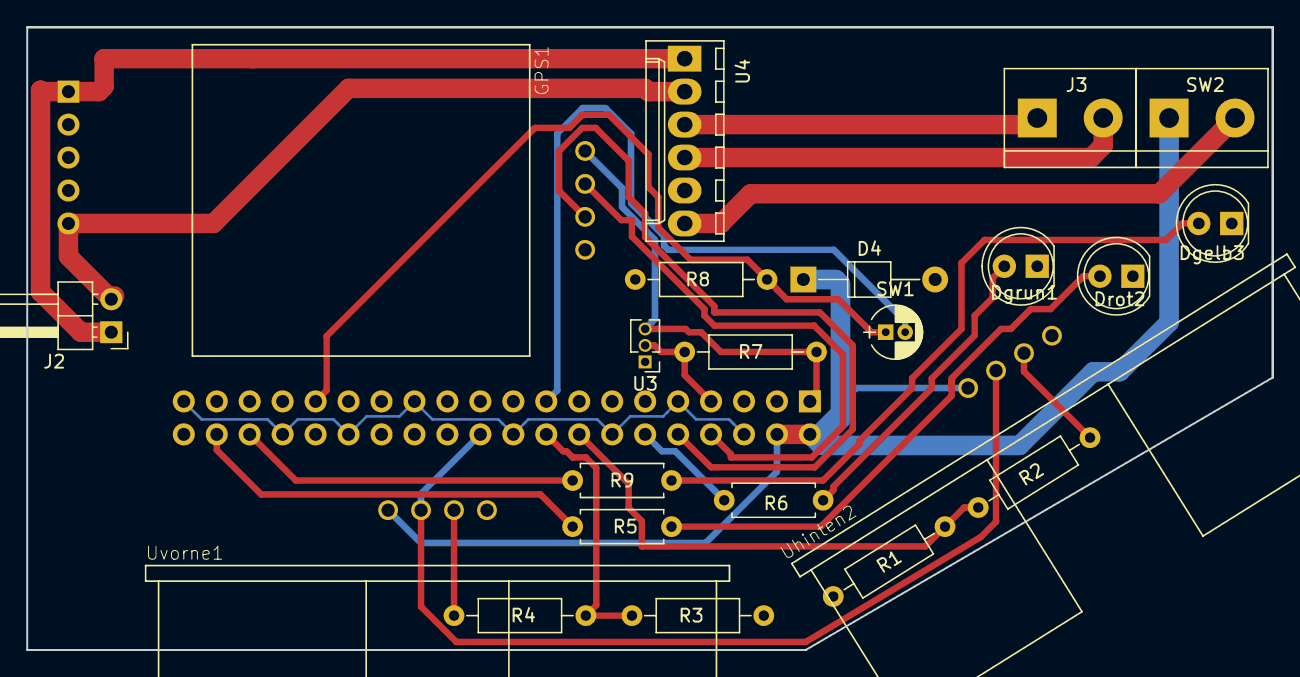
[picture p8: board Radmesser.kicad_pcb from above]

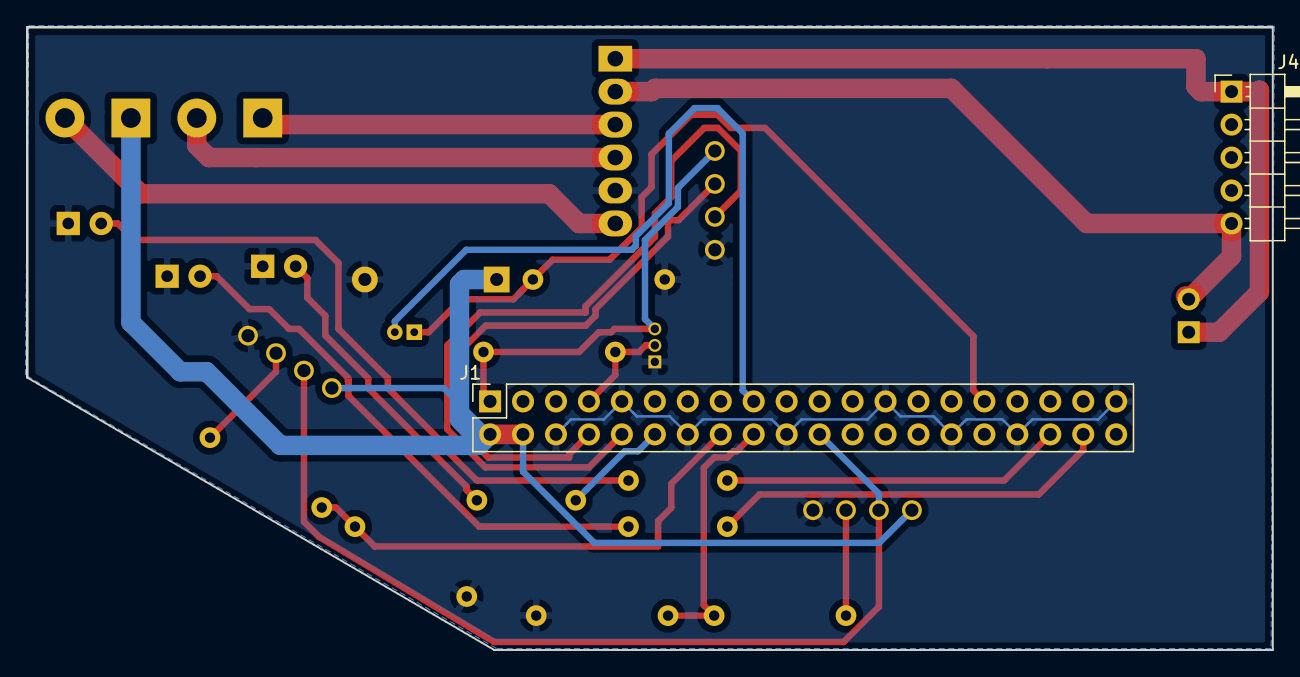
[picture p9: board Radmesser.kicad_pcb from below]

Board: 2 copper layers, 96.0 x 48.0 mm, 24 parts (2 on the bottom side), 24 nets.

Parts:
D4: Z5,1V; D_T-1_P10.16mm_Horizontal
Dgelb3: LED; LED_D5.0mm
Dgrun1: LED; LED_D5.0mm
Drot2: LED; LED_D5.0mm
GPS1: GY-GPS6MV2; GY-GPS6MV
J1: Raspberry_Pi_2_3; Raspi_Zero
J2: Conn_01x02_Female; Pin_Header_Angled_1x02_Pitch2.54mm
J3: Conn_01x02_Female; TerminalBlock_bornier-2_P5.08mm
J4: USB_B_Micro; Pin_Header_Angled_1x05_Pitch2.54mm
R1, R3: 1k; R_Axial_DIN0207_L6.3mm_D2.5mm_P10.16mm_Horizontal
R2, R4: 510; R_Axial_DIN0207_L6.3mm_D2.5mm_P10.16mm_Horizontal
R5, R6, R9: 100; R_Axial_DIN0207_L6.3mm_D2.5mm_P7.62mm_Horizontal
R7: 4,7k; R_Axial_DIN0207_L6.3mm_D2.5mm_P10.16mm_Horizontal
R8: 10k; R_Axial_DIN0207_L6.3mm_D2.5mm_P10.16mm_Horizontal
SW1: SW_DIP_x01; CP_Radial_D4.0mm_P1.50mm
SW2: SW_on_off; TerminalBlock_bornier-2_P5.08mm
U3: DS18B20; Pin_Header_Straight_1x03_Pitch1.27mm
U4: Battery_Charging; BatCharging
Uhinten2: HC-SR04; XCVR_HC-SR04
Uvorne1: HC-SR04; XCVR_HC-SR04

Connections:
GND: D4.2, Dgelb3.1, Dgrun1.1, Drot2.1, GPS1.4, J1.6, J1.9, J1.14, J1.20, J1.25, J1.30, J1.34, J1.39, R1.2, R3.2, R8.2, U3.1, U4.5, Uhinten2.4, Uvorne1.4
unnamed: D4.1, J1.2, J1.4, SW2.1, Uhinten2.1, Uvorne1.1
unnamed: Dgelb3.2, R9.2
unnamed: Dgrun1.2, R6.2
unnamed: Drot2.2, R5.2
unnamed: GPS1.1, J1.1, R7.1, U3.3
unnamed: GPS1.2, J1.8
unnamed: GPS1.3, J1.10
unnamed: J1.7, R7.2, U3.2
unnamed: J1.12, R6.1
unnamed: J1.16, R1.1, R2.2
unnamed: J1.17, SW1.2
unnamed: J1.18, R3.1, R4.2
unnamed: J1.22, Uhinten2.2, Uvorne1.2
unnamed: J1.31, R8.1, SW1.1
unnamed: J1.36, R9.1
unnamed: J1.38, R5.1
unnamed: J2.1, J4.1, U4.1
unnamed: J2.2, J4.5, U4.2
unnamed: J3.1, U4.3
unnamed: J3.2, U4.4
unnamed: R2.1, Uhinten2.3
unnamed: R4.1, Uvorne1.3
unnamed: SW2.2, U4.6

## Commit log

2021-03-03 Changes to upset part one
    [Ueberholvorgaenge_detailliert_2.csv, erkannte.csv]
2021-03-10 readme created, added sample data
2021-05-02 KiCad files added
    [Radmesser-B.Cu.gbr, Radmesser-B.Mask.gbr, Radmesser-B.Paste.gbr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]
2021-05-04 PCB-Files moved to Hardware folder
    [Radmesser-B.Cu.gbr, Radmesser-B.Mask.gbr, Radmesser-B.Paste.gbr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]
2021-05-05 added PCB-Files
2021-05-10 3d-print-data added
    [1.4_Deckel.stl, 1.4_Gehäuse.stl, 1.4_USB_Stopfen.stl]
